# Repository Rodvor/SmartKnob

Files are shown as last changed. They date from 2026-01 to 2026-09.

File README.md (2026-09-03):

**Smart haptic knob as computer (MacOS) HID**

Still in development.

## Build dependencies

The following older versions are the **known-good fallback**:

| Component | Version | Notes |
| --- | --- | --- |
| [Arduino IDE](https://www.arduino.cc/en/software) | 2.3.6 | Includes Arduino CLI 1.2.0 |
| [Espressif Arduino-ESP32](https://github.com/espressif/arduino-esp32) | 3.2.1 | Board: `ESP32 Dev Module` (`esp32:esp32:esp32`) |
| [NimBLE-Arduino](https://github.com/h2zero/NimBLE-Arduino) | 2.3.9 | Install through Arduino Library Manager |
| [TFT_eSPI](https://github.com/Bodmer/TFT_eSPI) | 2.5.43 | Install through Arduino Library Manager; configuration below is required |
| [Simple FOC](https://docs.simplefoc.com) | 2.3.5 | Install through Arduino Library Manager |

`Wire`, `LittleFS`, and FreeRTOS are supplied by the Arduino-ESP32 board package and do not need separate installation.

To restore the known-good versions with Arduino CLI:

```sh
arduino-cli core install esp32:esp32@3.2.1
arduino-cli lib install "NimBLE-Arduino@2.3.9" "TFT_eSPI@2.5.43" "Simple FOC@2.3.5"
```

After restoring TFT_eSPI, replace its `User_Setup.h` with the repository copy at [`config/TFT_eSPI_User_Setup.h`](config/TFT_eSPI_User_Setup.h).

### Current upgraded versions

Installed, compile-checked, and flash-verified on 2026-09-03:

| Component | Current version |
| --- | --- |
| Espressif Arduino-ESP32 | 3.3.11 |
| NimBLE-Arduino | 2.5.1 |
| TFT_eSPI | 2.5.43 (already current) |
| Simple FOC | 2.4.0 |

The complete upgraded set compiles successfully for `ESP32 Dev Module`. ESP32 core 3.3.11 also compiles with the known-good older libraries, but upgrading ESP32 and Simple FOC together is recommended because Simple FOC 2.4.0 explicitly adds compatibility with all Arduino-ESP32 3.x releases.

NimBLE-Arduino 2.4 and newer starts registered HID services through `NimBLEServer::start()`. Its old `NimBLEHIDDevice::startServices()` method is deprecated and scheduled for removal. `NimbleKeyboard.h` detects the NimBLE generation: it uses the server method with the current library, but retains the HID-specific call when compiling against the fallback NimBLE 2.3.9.

Compilation and flash verification prove API compatibility and image integrity, but not the hardware behavior. Before making the newer versions the new baseline, test Bluetooth pairing/reconnection, fine volume adjustment, display output, motor direction, and haptic torque on the physical device. Simple FOC 2.4.0 changes ESP32 PWM safety/timing and velocity calculation, while ESP32 core 3.3.11 moves from ESP-IDF 5.4 to 5.5.5.

### Duplicate library files after an update

If a build error names files such as `HybridStepperMotor 2.cpp` or `NimBLEDevice 2.cpp`, the Arduino library directory contains duplicate conflict copies. Arduino compiles every `.cpp` file below a library's `src` directory, so these old copies are compiled alongside the newly installed version and cause duplicate definitions or incompatible APIs.

Move the `* 2.cpp` and `* 2.h` files out of the active library directory, or remove and cleanly reinstall that library. Do not fix this by editing the duplicated source files: they are stale library copies rather than project code.

### TFT_eSPI configuration

TFT_eSPI uses a library-level configuration that can be overwritten by an update or reinstall. The canonical setup is stored in [`config/TFT_eSPI_User_Setup.h`](config/TFT_eSPI_User_Setup.h); copy it over `Arduino/libraries/TFT_eSPI/User_Setup.h`.

```cpp
#define GC9A01_DRIVER

#define TFT_CS    5
#define TFT_DC    4
#define TFT_RST   0
#define TFT_MOSI  16
#define TFT_SCLK  15
#define TFT_BL    2

#define LOAD_GLCD
#define LOAD_FONT2
#define LOAD_FONT4
#define LOAD_FONT6
#define LOAD_FONT7
#define LOAD_FONT8
#define LOAD_GFXFF
#define SMOOTH_FONT
#define SPI_FREQUENCY       27000000
#define SPI_READ_FREQUENCY  20000000
#define SPI_TOUCH_FREQUENCY 2500000
```

ESP32 to drive TFT touch display
SimpleFOC mini v1.0 to drive brushless motor
AS5600 magnetic encoder to read brushless motor angle

ESP32 works as a bluetooth keyboard and takes input from dial and touch input from screen. 
Screen next to knob models are final for now.

**Current controls:**
- Move between menus using swipe gesture left or right
- Volume menu: Dial for adjustment, tap for play/pause
- Discord menu: Dial for unmute, mute, deafen and tap for leaving VC
- Brightness menu: Dial for adjusting screen brightness
- Media menu: Dial for skip/previous media track, and tap for play/pause.

Volume and media are controlled using dedicated buttons e.g. KEY_MEDIA_VOLUME_UP

**Brightness (Mac):** 
- Up: F15
- Down: F14

**Keybinds for Discord (Configured in Discord Keybinds):**
- F13 -> Mute
- Alt + F13 -> Deafen
- Shift + Alt + F13 -> Disconnect

Images are from google and no rights have been requested. Personal use only.

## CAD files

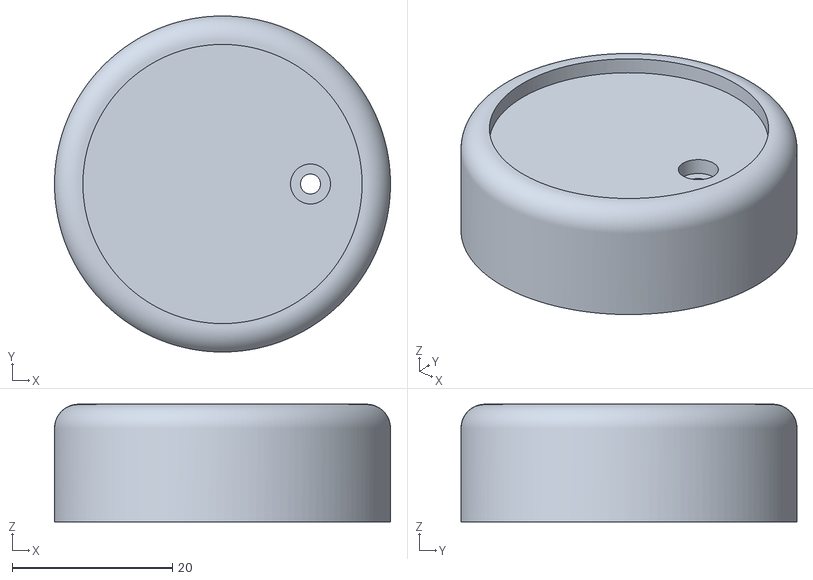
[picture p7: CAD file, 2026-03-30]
models/Dial and screen/Knob.stl
42.0 x 42.0 x 14.7

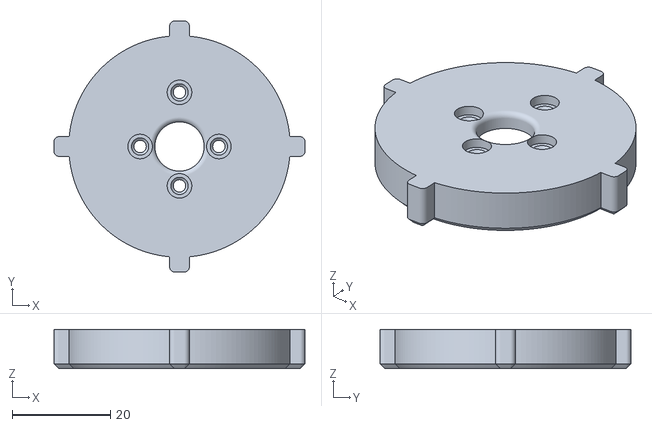
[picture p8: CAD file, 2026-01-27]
models/Dial on screen/Rotation base.stl
51.0 x 51.0 x 8.00

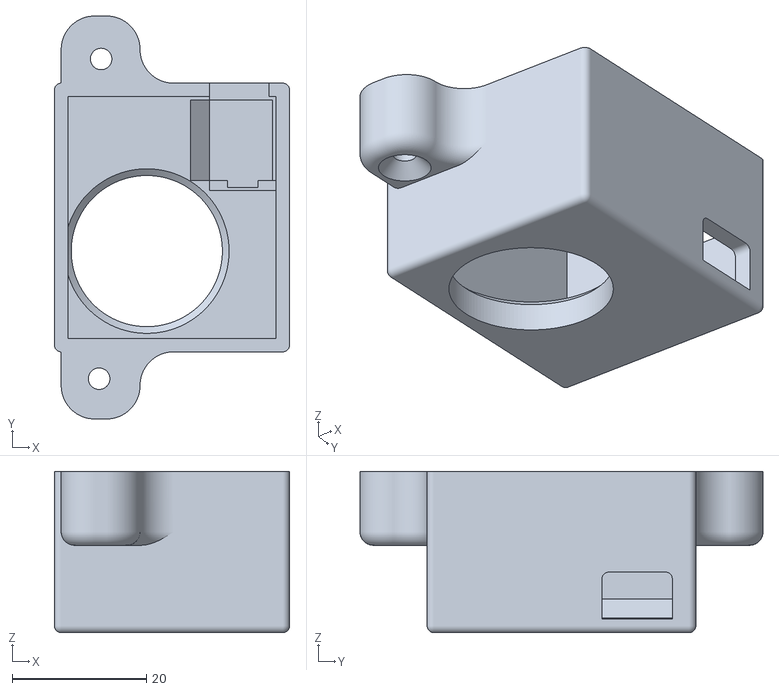
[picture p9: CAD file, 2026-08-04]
models/Knob powerbox.stl
35.0 x 60.0 x 24.0

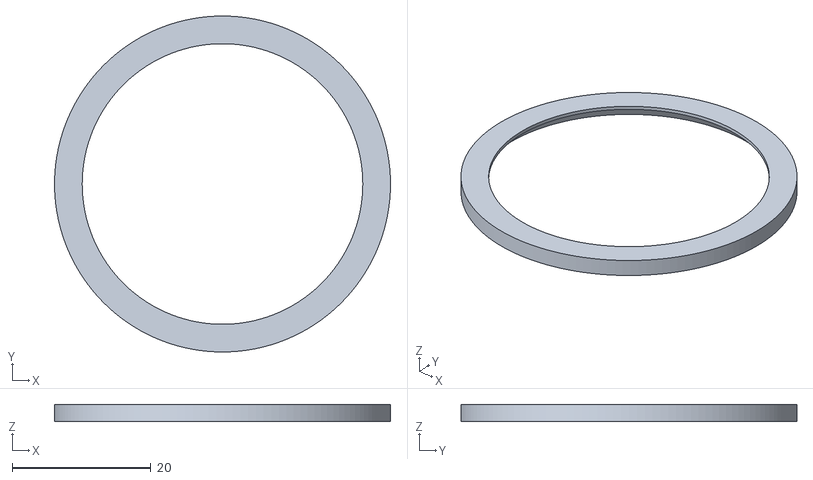
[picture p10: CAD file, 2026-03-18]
models/Dial and screen/Screen cover.stl
48.5 x 48.5 x 2.50

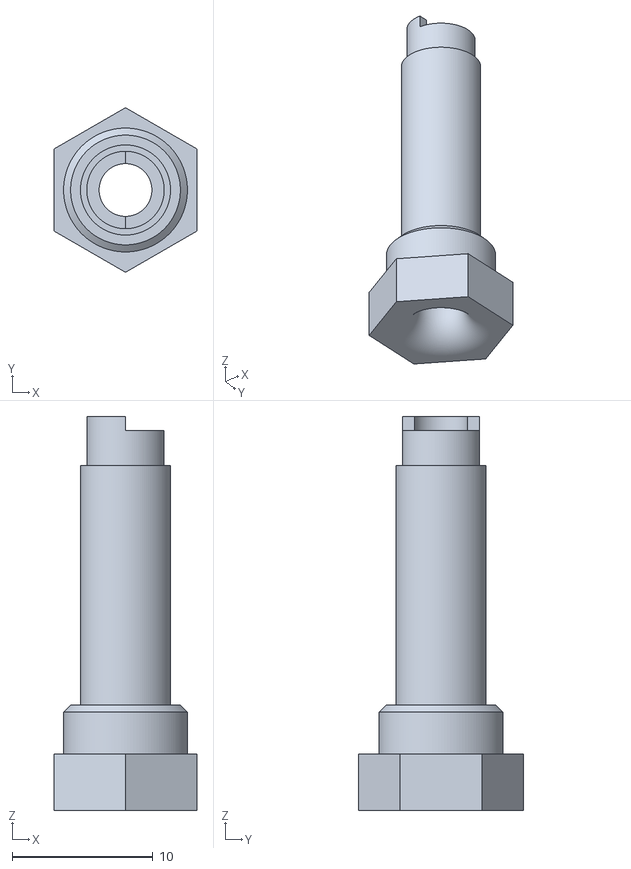
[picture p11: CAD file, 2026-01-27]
models/Dial on screen/Axle.stl
10.1 x 11.7 x 28.0

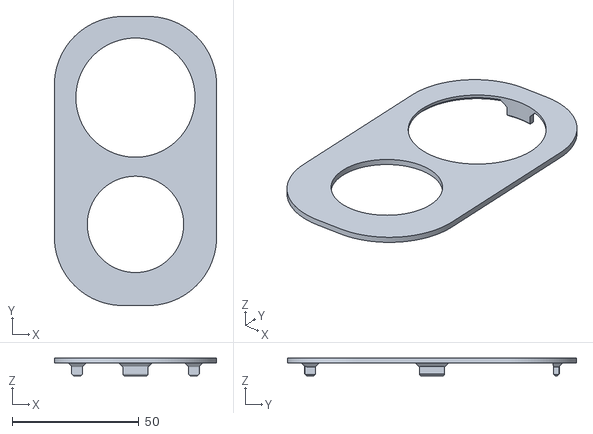
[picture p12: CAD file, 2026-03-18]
models/Dial and screen/Lid.stl
64.0 x 114.0 x 7.00

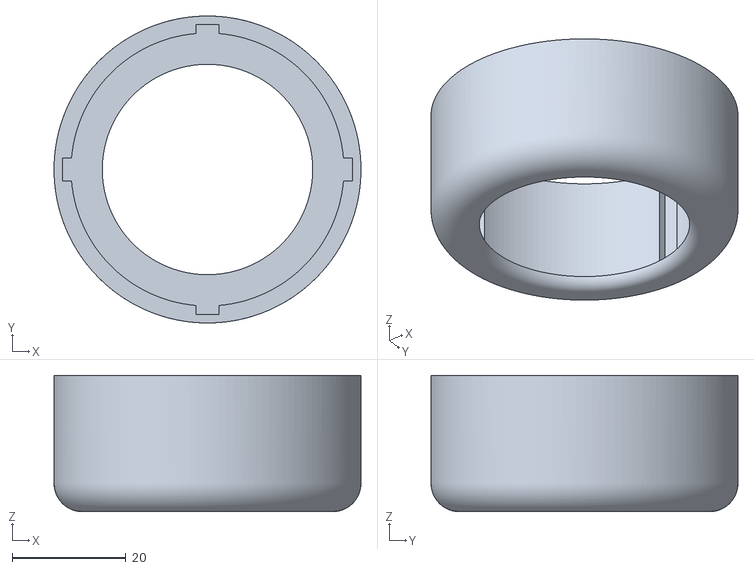
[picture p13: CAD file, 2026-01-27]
models/Dial on screen/dial.stl
54.0 x 54.0 x 24.0

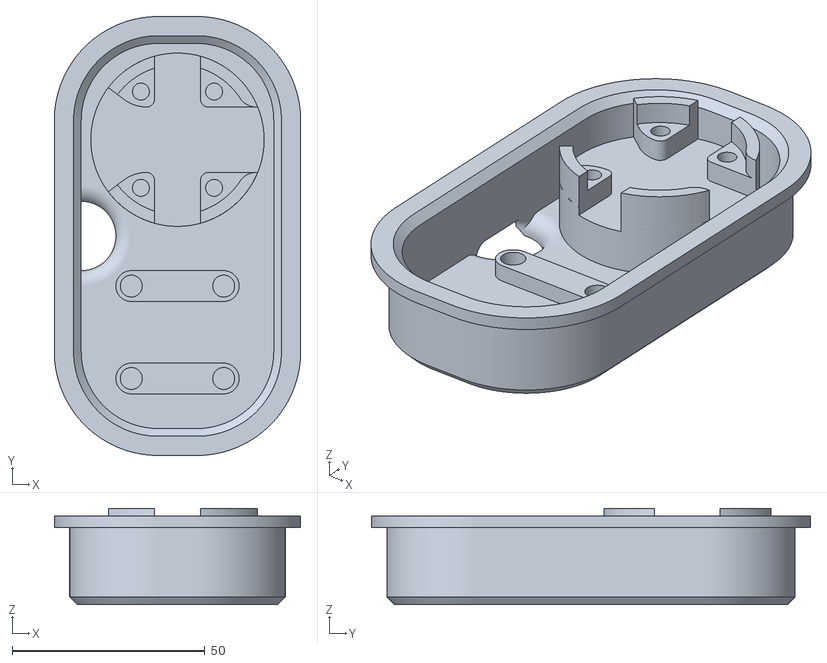
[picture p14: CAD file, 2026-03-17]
models/Dial and screen/Case.stl
64.0 x 114.0 x 25.0

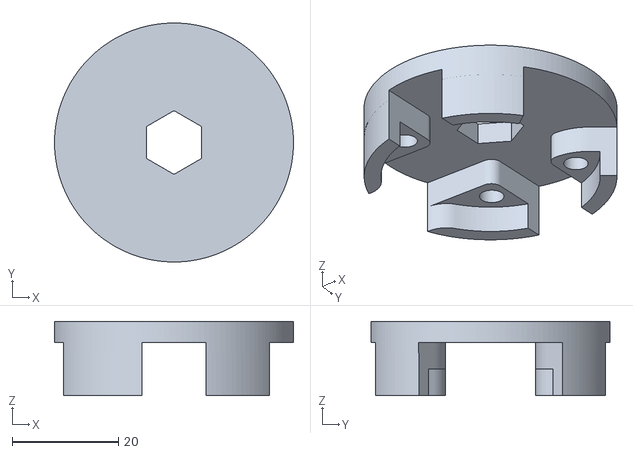
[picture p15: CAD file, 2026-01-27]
models/Dial on screen/Axle plate.stl
45.0 x 45.0 x 14.0

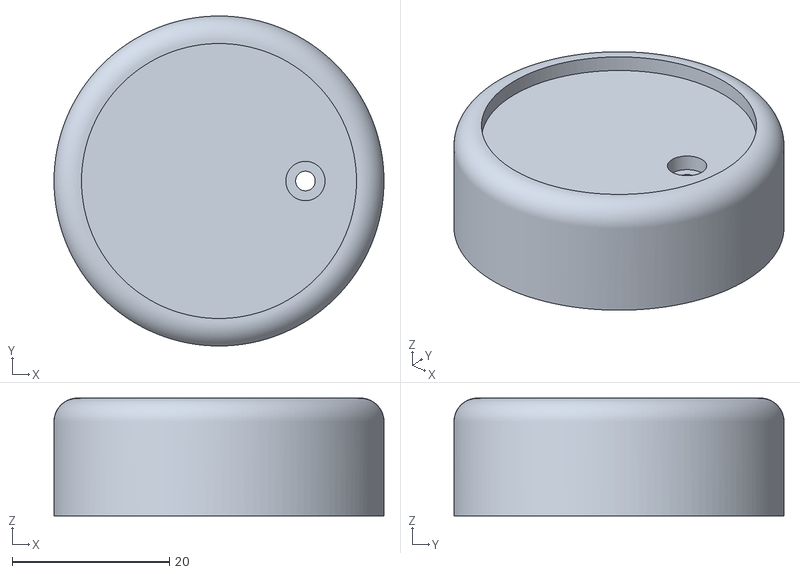
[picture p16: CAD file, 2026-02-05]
models/Dial and screen/Dial.stl
42.0 x 42.0 x 15.0

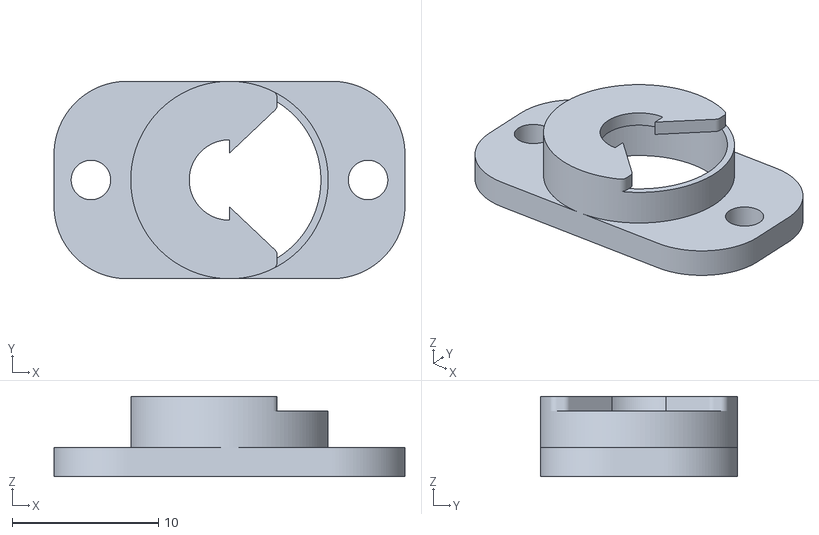
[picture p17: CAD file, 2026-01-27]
models/Dial on screen/Axle holder.stl
24.0 x 13.5 x 5.50

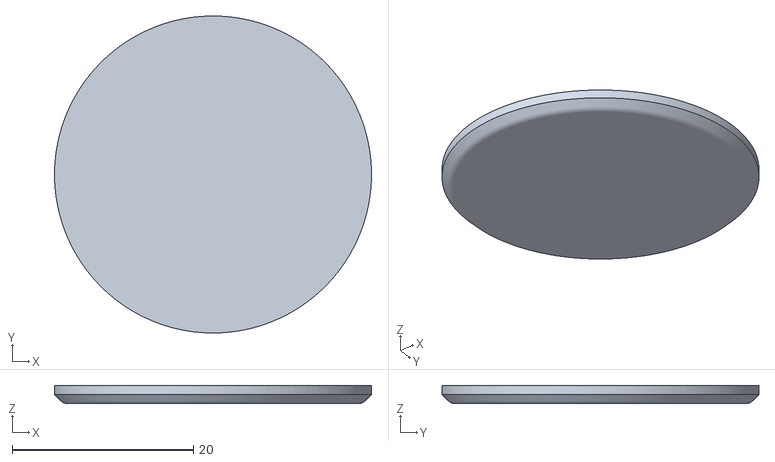
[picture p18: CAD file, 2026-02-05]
models/Dial and screen/Dial face.stl
35.0 x 35.0 x 2.00

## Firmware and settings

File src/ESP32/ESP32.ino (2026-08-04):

// Note: Colors for fonts using RGB565

// Include libraries
#include <TFT_eSPI.h>
#include <Wire.h>
#include <SimpleFOC.h>
#include <math.h>
#include "NimBLEKeyboard.h"

// Include configurations and icons
#include "menu_config.h"
#include "pin_config.h"
#include "icons.h"

#define CST816S_ADDR        0x15
#define CST816S_FINGER_REG  0x02
#define CST816S_X_HIGH_REG  0x03
#define CST816S_X_LOW_REG   0x04
#define CST816S_SWIPE_THRESHOLD 40

// Minimum torque. No torque if below this number
#define MINIMUM_TORQUE  0.1

// Moving ball sprite

#define BALL_RADIUS       5
#define BALL_SPRITE_SIZE  40   // 2*(BALL_RADIUS+margin) + headroom for movement per frame
#define SCREEN_SIZE       240  // adjust if your panel isn't 240x240
#define SPRITE_TRANSPARENT 0xF81F  // magenta marker, unused elsewhere in the UI

// Define objects
MagneticSensorI2C encoder = MagneticSensorI2C(AS5600_I2C);
TFT_eSPI tft = TFT_eSPI();
BLDCMotor motor = BLDCMotor(7);
BLDCDriver3PWM driver = BLDCDriver3PWM(IN1, IN2, IN3, EN);
NimBLEKeyboard bleKeyboard;

TFT_eSprite ballSprite = TFT_eSprite(&tft);

// For notches
const int cx = 120;
const int cy = 120;
const int radius = 120;
const int lineLength = 7;

// For motor calculations
float currentPos = 0;
float max_torque = 0.3;
float torque_build_up = 0.8;
int current_choice = 0;

// For UI logic
bool display_status = true;
bool take_input = false;
unsigned long last_activity = 0;
int current_ui_id = -1;
int new_ui_id = VOLUME_ID;
int n_lines = VOLUME_NOTCHES;
int discord_choice = 0;

const int CHOICES[] = {VOLUME_ID, MEDIA_ID, BRIGHT_ID, DISCORD_ID};
const int N_CHOICES = 4;
int current_menu_index = 0;

unsigned long last_touch_time = 0;
const unsigned long TOUCH_DEBOUNCE_MS = 300;
bool touch_active = false;
int touch_start_x = -1;
int touch_end_x = -1;

float sleep_pos = 0;
#define WAKE_ROTATION_THRESHOLD (PI / 60.0)

TaskHandle_t focTask;

void focLoop(void* param) {
  for (;;) {
    motor.loopFOC();
    vTaskDelay(1);
  }
}

uint8_t readTouchReg(uint8_t reg) {
  Wire.beginTransmission(CST816S_ADDR);
  Wire.write(reg);
  Wire.endTransmission(false);
  Wire.requestFrom(CST816S_ADDR, (uint8_t)1);
  if (Wire.available()) return Wire.read();
  return 0;
}

uint8_t readTouchFingers() { return readTouchReg(CST816S_FINGER_REG); }

int readTouchX() {
  uint8_t hi = readTouchReg(CST816S_X_HIGH_REG) & 0x0F;
  uint8_t lo = readTouchReg(CST816S_X_LOW_REG);
  return (hi << 8) | lo;
}

void dumpBleLog() {
  if (!LittleFS.begin(false)) return;
  fs::File f = LittleFS.open("/ble_log.txt", "r");
  if (!f) {
    Serial.println("No BLE log found.");
    return;
  }
  Serial.println("=== BLE LOG ===");
  while (f.available()) {
    Serial.write(f.read());
  }
  Serial.println("=== END LOG ===");
  f.close();
}

void setup() {
  Serial.begin(115200);
  //delay(500); // give Serial monitor time to connect
  //dumpBleLog();

  bleKeyboard.begin("Haptic Knob");

  // Set blacklight pins
  pinMode(BLK_PIN, OUTPUT);
  digitalWrite(BLK_PIN, HIGH);

  // Init screen
  tft.init();
  tft.fillScreen(TFT_BLACK);
  tft.setFreeFont(&FreeSans12pt7b);
  tft.setTextDatum(MC_DATUM);
  tft.setTextColor(0xad75);
  // Ball sprite
  ballSprite.setColorDepth(16);
  ballSprite.createSprite(BALL_SPRITE_SIZE, BALL_SPRITE_SIZE);

  // Bluetooth connecting screen
  tft.fillScreen(TFT_BLACK);
  tft.drawBitmap(ICON_X, ICON_Y, icon_bluetooth, ICON_W, ICON_H, BLUETOOTH_COLOR);
  tft.drawString("Connecting...", 122, 180);


  Wire.begin(ENCODER_SDA, ENCODER_SCL);
  encoder.init();

  pinMode(TP_RST, OUTPUT);
  digitalWrite(TP_RST, LOW);
  delay(10);
  digitalWrite(TP_RST, HIGH);
  delay(50);
  pinMode(TP_INT, INPUT);
  Wire1.begin(TP_SDA, TP_SCL);

  driver.voltage_power_supply = 12.0;
  driver.init();
  motor.linkDriver(&driver);
  motor.linkSensor(&encoder);
  motor.controller = MotionControlType::torque;
  motor.torque_controller = TorqueControlType::voltage;
  motor.voltage_limit = 3.0;
  motor.init();
  motor.initFOC();

  xTaskCreatePinnedToCore(focLoop, "FOC", 4096, NULL, 1, &focTask, 1);

  while (!bleKeyboard.isConnected()) {
    delay(500);
  }

  Serial.println("BLE connected, starting UI");
}

void doTapAction() {
  if (!bleKeyboard.isConnected()) return;
  if      (current_ui_id == VOLUME_ID)  bleKeyboard.playPause();
  else if (current_ui_id == MEDIA_ID)   bleKeyboard.playPause();
  else if (current_ui_id == DISCORD_ID) bleKeyboard.pressShiftAltF13();
  // BRIGHT_ID: no tap action
}

void swipeToMenu(int direction) {
  current_menu_index = (current_menu_index + direction + N_CHOICES) % N_CHOICES;
  new_ui_id = CHOICES[current_menu_index];
  last_activity = millis();
}

void handleTouchRevised() {
  unsigned long now = millis();
  uint8_t fingers = readTouchFingers();

  if (fingers >= 1) {
    int x = readTouchX();
    if (!touch_active) { touch_active = true; touch_start_x = x; }
    touch_end_x = x;
  } else {
    if (touch_active) {
      touch_active = false;
      if (now - last_touch_time < TOUCH_DEBOUNCE_MS) return;
      last_touch_time = now;

      if (!display_status) {
        setDisplay(true);
        last_activity = now;
        return;
      }

      int dx = touch_end_x - touch_start_x;
      if      (dx >  CST816S_SWIPE_THRESHOLD) swipeToMenu(+1);
      else if (dx < -CST816S_SWIPE_THRESHOLD) swipeToMenu(-1);
      else { doTapAction(); last_activity = now; }
    }
  }
}

void loop() {
  handleTouchRevised();

  if (new_ui_id != current_ui_id) {
    drawUI(new_ui_id);
    take_input = false;
  }

  float pos = encoder.getAngle();
  int choice = calc_choice(pos);

  if (take_input) {
    motor.move(calc_torque(pos));
  } else {
    float target_angle = 0;
    if (current_ui_id == DISCORD_ID) target_angle = discord_choice * 2 * PI / 3;
    motor.move(torque_to_angle(pos, target_angle));
    if (abs(((target_angle - PI / 2) - pos)) < 0.05) {
      take_input = true;
      current_choice = choice;
    }
  }

  if (pos != currentPos) {

    if (!display_status && fabs(pos - sleep_pos) > WAKE_ROTATION_THRESHOLD) {
      setDisplay(true);
      last_activity = millis();
    }

    drawBall(currentPos, pos);

    int new_choice = calc_choice(pos);

    if (new_choice != current_choice && take_input) {
      if (pos > currentPos) {
        if      (current_ui_id == VOLUME_ID)  bleKeyboard.volumeUp();
        else if (current_ui_id == MEDIA_ID)   bleKeyboard.nextTrack();
        else if (current_ui_id == BRIGHT_ID)  bleKeyboard.pressF15();
      } else {
        if      (current_ui_id == VOLUME_ID)  bleKeyboard.volumeDown();
        else if (current_ui_id == MEDIA_ID)   bleKeyboard.prevTrack();
        else if (current_ui_id == BRIGHT_ID)  bleKeyboard.pressF14();
      }

      if (current_ui_id == DISCORD_ID) {
        if (new_choice == 0) {
          bleKeyboard.pressF13();
        } else if (new_choice == 1 && current_choice == 0) {
          bleKeyboard.pressF13();
        } else if (new_choice == 2 && current_choice == 0) {
          bleKeyboard.pressF13(); delay(20); bleKeyboard.pressAltF13();
        } else {
          bleKeyboard.pressAltF13();
        }
        discord_choice = new_choice;
      }

      if (!display_status) setDisplay(true);
      last_activity = millis();
      current_choice = new_choice;
    }

    currentPos = pos;
  }

  if (display_status && millis() - last_activity > IDLE_TIMEOUT * 60000) {
    setDisplay(false);
  }

  vTaskDelay(1); // yield instead of blocking delay
}

// --- UI ---

void drawMenuIcon(int id) {
  const uint8_t* bmp = nullptr;
  unsigned int color = TFT_WHITE;
  switch (id) {
    case VOLUME_ID:  bmp = icon_volume;     color = VOLUME_COLOR;  break;
    case MEDIA_ID:   bmp = icon_media;      color = MEDIA_COLOR;   break;
    case DISCORD_ID: bmp = icon_discord;    color = DISCORD_COLOR; break;
    case BRIGHT_ID:  bmp = icon_brightness; color = BRIGHT_COLOR;  break;
  }
  if (bmp) {
    tft.drawBitmap(ICON_X, ICON_Y, bmp, ICON_W, ICON_H, color);
  }
}

void drawSmallIcon(int id, int x, int y) {
  const uint8_t* bmp = nullptr;
  unsigned int color = TFT_WHITE;
  switch (id) {
    case UNMUTE_ID:  bmp = icon_unmute;   color = UNMUTE_COLOR;  break;
    case MUTE_ID:   bmp = icon_mute;      color = MUTE_COLOR;   break;
    case DEAFEN_ID: bmp = icon_deafen;    color = DEAFEN_COLOR; break;
  }
  if (bmp) {
    tft.drawBitmap(x, y, bmp, SMALL_ICON_W, SMALL_ICON_H, color);
  }
}

void drawUI(int id) {
  tft.fillScreen(TFT_BLACK);
  current_ui_id = id;
  drawMenuIcon(id);
  tft.setFreeFont(&FreeSans12pt7b);
  tft.setTextDatum(MC_DATUM);
  tft.setTextColor(0xad75);
  if      (id == VOLUME_ID)  { tft.drawString("Volume",     120, 180); max_torque = VOLUME_TORQUE;  torque_build_up = VOLUME_BUILDUP;  n_lines = VOLUME_NOTCHES; }
  else if (id == MEDIA_ID)   { tft.drawString("Media",      120, 180); max_torque = MEDIA_TORQUE;   torque_build_up = MEDIA_BUILDUP;   n_lines = MEDIA_NOTCHES; }
  else if (id == DISCORD_ID) { 
    tft.drawString("Discord", 120, 180);
    drawSmallIcon(UNMUTE_ID, 108, 30);
    drawSmallIcon(MUTE_ID, 178, 155);
    drawSmallIcon(DEAFEN_ID, 44, 155);
    max_torque = DISCORD_TORQUE; 
    torque_build_up = DISCORD_BUILDUP; 
    n_lines = DISCORD_NOTCHES; 
    }
  else if (id == BRIGHT_ID)  { tft.drawString("Brightness", 120, 180); max_torque = BRIGHT_TORQUE;  torque_build_up = BRIGHT_BUILDUP;  n_lines = BRIGHT_NOTCHES; }
  drawClockLines();
}

void drawClockLines() {
  for (int i = 0; i < n_lines; i++) {
    float angle = i * (2.0 * PI / n_lines) - PI / 2;
    int x0 = round(cx + radius * cos(angle));
    int y0 = round(cy + radius * sin(angle));
    int x1 = round(cx + (radius - lineLength) * cos(angle));
    int y1 = round(cy + (radius - lineLength) * sin(angle));
    tft.drawLine(x0, y0, x1, y1, 0x9492);
  }
}

float calc_torque(float pos) {
  const float amplitude = torque_build_up * max_torque;
  const float inside_tan = 0.5 * n_lines * (pos + PI / 2);
  float torque = amplitude * tan(inside_tan);

  if (abs(torque) < MINIMUM_TORQUE) return 0.0;
  if (torque > max_torque) return max_torque;
  if (torque < -max_torque) return -max_torque;
  return torque;
}

float torque_to_angle(float pos, float angle) {
  return 0.5 * cbrt(pos + PI / 2 - angle);
}

int calc_choice(float pos) {
  float angle = pos + PI / 2;
  while (angle < 0) angle += 2 * PI;
  while (angle >= 2 * PI) angle -= 2 * PI;
  return ((int)round(angle / (2.0 * PI) * n_lines)) % n_lines;
}

void drawBall(float posOld, float posNew) {
  int xOld = round(cx + (radius - 18) * cos(posOld));
  int yOld = round(cy + (radius - 18) * sin(posOld));
  int xNew = round(cx + (radius - 18) * cos(posNew));
  int yNew = round(cy + (radius - 18) * sin(posNew));

  const int margin = 2;
  int minX = min(xOld, xNew) - BALL_RADIUS - margin;
  int minY = min(yOld, yNew) - BALL_RADIUS - margin;
  int maxX = max(xOld, xNew) + BALL_RADIUS + margin;
  int maxY = max(yOld, yNew) + BALL_RADIUS + margin;
  int w = maxX - minX;
  int h = maxY - minY;

  if (w <= BALL_SPRITE_SIZE && h <= BALL_SPRITE_SIZE) {
    minX = constrain(minX, 0, SCREEN_SIZE - BALL_SPRITE_SIZE);
    minY = constrain(minY, 0, SCREEN_SIZE - BALL_SPRITE_SIZE);

    ballSprite.fillSprite(SPRITE_TRANSPARENT);
    ballSprite.fillCircle(xOld - minX, yOld - minY, BALL_RADIUS, TFT_BLACK);
    ballSprite.fillCircle(xNew - minX, yNew - minY, BALL_RADIUS, TFT_WHITE);
    ballSprite.pushSprite(minX, minY, SPRITE_TRANSPARENT);
  } else {
    tft.fillCircle(xOld, yOld, BALL_RADIUS, TFT_BLACK);
    tft.fillCircle(xNew, yNew, BALL_RADIUS, TFT_WHITE);
  }
}

void setDisplay(bool onoff) {
  display_status = onoff;
  if (!onoff) sleep_pos = encoder.getAngle();
  digitalWrite(BLK_PIN, onoff ? HIGH : LOW);
}

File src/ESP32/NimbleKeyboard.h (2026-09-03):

#pragma once

#include <NimBLEDevice.h>
#include <NimBLEServer.h>
#include <NimBLEUtils.h>
#include <NimBLEHIDDevice.h>
#if __has_include(<NimBLECppVersion.h>)
#include <NimBLECppVersion.h>
#define SMARTKNOB_HAS_NIMBLE_VERSION_HEADER 1
#endif
#include <HIDTypes.h>
#include <LittleFS.h>
#include <atomic>
#include <freertos/queue.h>

// Consumer key codes
#define KEY_MEDIA_VOLUME_UP      0xE9
#define KEY_MEDIA_VOLUME_DOWN    0xEA
#define KEY_MEDIA_PLAY_PAUSE     0xCD
#define KEY_MEDIA_NEXT_TRACK     0xB5
#define KEY_MEDIA_PREVIOUS_TRACK 0xB6

// HID report descriptor: keyboard + consumer control
static const uint8_t hidReportDescriptor[] = {
  // Keyboard
  0x05, 0x01,  // Usage Page: Generic Desktop
  0x09, 0x06,  // Usage: Keyboard
  0xA1, 0x01,  // Collection: Application
  0x85, 0x01,  //   Report ID: 1
  0x05, 0x07,  //   Usage Page: Keyboard
  0x19, 0xE0,  //   Usage Minimum: Left Control
  0x29, 0xE7,  //   Usage Maximum: Right GUI
  0x15, 0x00,  //   Logical Minimum: 0
  0x25, 0x01,  //   Logical Maximum: 1
  0x75, 0x01,  //   Report Size: 1
  0x95, 0x08,  //   Report Count: 8
  0x81, 0x02,  //   Input: Data, Variable, Absolute (modifier keys)
  0x95, 0x01,  //   Report Count: 1
  0x75, 0x08,  //   Report Size: 8
  0x81, 0x03,  //   Input: Constant (reserved)
  0x95, 0x06,  //   Report Count: 6
  0x75, 0x08,  //   Report Size: 8
  0x15, 0x00,  //   Logical Minimum: 0
  0x25, 0x73,  //   Logical Maximum: 115
  0x05, 0x07,  //   Usage Page: Keyboard
  0x19, 0x00,  //   Usage Minimum: 0
  0x29, 0x73,  //   Usage Maximum: 115
  0x81, 0x00,  //   Input: Data, Array
  0xC0,        // End Collection

  // Consumer Control
  0x05, 0x0C,  // Usage Page: Consumer
  0x09, 0x01,  // Usage: Consumer Control
  0xA1, 0x01,  // Collection: Application
  0x85, 0x02,  //   Report ID: 2
  0x15, 0x00,  //   Logical Minimum: 0
  0x26, 0xFF, 0x03, // Logical Maximum: 1023
  0x19, 0x00,  //   Usage Minimum: 0
  0x2A, 0xFF, 0x03, // Usage Maximum: 1023
  0x75, 0x10,  //   Report Size: 16
  0x95, 0x01,  //   Report Count: 1
  0x81, 0x00,  //   Input: Data, Array
  0xC0         // End Collection
};

// Modifier bitmasks
#define MOD_LEFT_CTRL   0x01
#define MOD_LEFT_SHIFT  0x02
#define MOD_LEFT_ALT    0x04
#define MOD_LEFT_GUI    0x08

// Keep Shift+Option held between volume ticks. They are released after this
// much time without a new volume turn.
static constexpr uint32_t VOLUME_MODIFIER_IDLE_RELEASE_MS = 500;

// Key codes (subset)
#define HID_KEY_F13  0x68
#define HID_KEY_F14  0x69
#define HID_KEY_F15  0x6A

class NimBLEKeyboard : public NimBLEServerCallbacks, public NimBLECharacteristicCallbacks {
public:
  NimBLEServer*    pServer    = nullptr;
  NimBLEHIDDevice* hid        = nullptr;
  NimBLECharacteristic* input = nullptr;
  NimBLECharacteristic* consumer = nullptr;

  uint32_t connectedSince = 0;
  bool loggingReady = false;

  static const size_t MAX_LOG_SIZE = 8192;

  void logEvent(const char* msg) {
    if (!loggingReady) return;
    fs::File f = LittleFS.open("/ble_log.txt", "a");
    if (!f) return;
    // Check size and truncate if too large
    if (f.size() > MAX_LOG_SIZE) {
      f.close();
      LittleFS.remove("/ble_log.txt");
      f = LittleFS.open("/ble_log.txt", "a");
      if (!f) return;
      f.println("[log truncated]");
    }
    unsigned long s = millis() / 1000;
    unsigned long m = s / 60;
    unsigned long h = m / 60;
    f.printf("[%02lu:%02lu:%02lu] %s\n", h % 100, m % 60, s % 60, msg);
    f.close();
  }

  void onConnect(NimBLEServer* s, NimBLEConnInfo& info) override {
    connected.store(false);
    keyboardSubscribed.store(false);
    consumerSubscribed.store(false);
    connectionGeneration.fetch_add(1);
    if (reportQueue) xQueueReset(reportQueue);
    connHandle.store(info.getConnHandle());
    connectedSince = millis();
    connected.store(true);
    Serial.println("BLE connected");
    logEvent("Connected");
    // Let the host choose connection parameters. Forcing a renegotiation here has
    // caused timeout disconnects with macOS.
  }

  void onDisconnect(NimBLEServer* s, NimBLEConnInfo& info, int reason) override {
    connected.store(false);
    keyboardSubscribed.store(false);
    consumerSubscribed.store(false);
    connectionGeneration.fetch_add(1);
    if (reportQueue) xQueueReset(reportQueue);
    uint32_t duration = (millis() - connectedSince) / 1000;
    char buf[80];
    snprintf(buf, sizeof(buf), "Disconnected reason=0x%02X, duration=%lus", reason, duration);
    Serial.println(buf);
    logEvent(buf);
  }

  void onSubscribe(NimBLECharacteristic* chr, NimBLEConnInfo& info, uint16_t subValue) override {
    const bool notificationsEnabled = (subValue & 0x01) != 0;
    if (chr == input) {
      keyboardSubscribed.store(notificationsEnabled);
      if (notificationsEnabled) enqueueRelease(input, 8);
    } else if (chr == consumer) {
      consumerSubscribed.store(notificationsEnabled);
      if (notificationsEnabled) enqueueRelease(consumer, 2);
    }
  }
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

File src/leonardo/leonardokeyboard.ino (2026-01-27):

/*
  Rotary encoder as HID media controller (macOS compatible)
  ---------------------------------------------------------
  Rotation:  volume up/down  (with Shift + Option)
  Button:
    - Single click → F13
    - Hold (>0.5 s) → pause/play immediately

  

  Switch: F13
*/

#include <HID-Project.h>
#include <SoftwareSerial.h>

SoftwareSerial espSerial(8, 9); // RX, TX

#define CLK 2
#define DT 3
#define SW 4
#define SWITCH_PIN 6


int lastCLK;
int lastSW;

// --- click timing ---
bool buttonPressed = false;
bool isHold = false;

bool switchState = false;
bool lastSwitchState = false;
unsigned long lastSwitchChange = 0;
const unsigned long debounceTime = 30;
static unsigned long lastKeepalive = 0;





void setup() {

  Consumer.begin();
  BootKeyboard.begin();

  pinMode(CLK, INPUT_PULLUP);
  pinMode(DT, INPUT_PULLUP);
  pinMode(SW, INPUT_PULLUP);

  lastCLK = digitalRead(CLK);
  lastSW  = digitalRead(SW);

  pinMode(SWITCH_PIN, INPUT_PULLUP);
  switchState = !digitalRead(SWITCH_PIN);
  lastSwitchState = switchState;

  Serial.begin(115200); // USB debug
  espSerial.begin(57600);

}






void loop() {

  // ---- Rotary push button ----
  int currentSW = digitalRead(SW);
  unsigned long now = millis();

  // Button pressed
  if (currentSW == LOW && !buttonPressed) {
    buttonPressed = true;
  }

  // Button released
  if (currentSW == HIGH && buttonPressed) {
    buttonPressed = false;

    if (!isHold) {
      clickEncoder(); // only click
    }

    isHold = false;

    delay(50);

  }

  lastSW = currentSW;


  // Encoder rotation
  int currentCLK = digitalRead(CLK);
  if (currentCLK != lastCLK) {
    if (digitalRead(DT) != currentCLK) {

      if (!buttonPressed) {
        // Only rotation
        volumeUp();
      } else {
        // Press and rotate
        skipNext();
        isHold = true;
      }
    } else {
      if (!buttonPressed) {
        // Only rotation
        volumeDown();
      } else {
        // Press and rotate
        skipPrevious();
        isHold = true;
      }
    }
  }
  lastCLK = currentCLK;





  // ---- On/Off Toggle Switch ----
  bool raw = !digitalRead(SWITCH_PIN);

  if (raw != lastSwitchState && (now - lastSwitchChange) > debounceTime) {
      lastSwitchChange = now;
      lastSwitchState = raw;

      if (raw != switchState) {
          switchState = raw;

          if (switchState) {
              switchOn();
          } else {
              switchOff();
          }
      }
  }

  // Function for keeping HID connected

  if (millis() - lastKeepalive > 30000) {
    BootKeyboard.releaseAll();
    lastKeepalive = millis();
  }

  if (espSerial.available()) {
    String cmd = espSerial.readStringUntil('\n');

    handleCommand(cmd);
  }
}

// ------------------------------------------------------
// Helper functions
// ------------------------------------------------------

void handleCommand(String c) {
  Serial.print("Handling: ");
  Serial.println(c);

  if (c.indexOf("volume-up") != -1) {
    volumeUp();
  } 
  else if (c.indexOf("volume-down") != -1) {
    volumeDown();
  }
  else if (c.indexOf("skip") != -1) {
    skipNext();
  }
  else if (c.indexOf("previous") != -1) {
    skipPrevious();
  }
  else if (c.indexOf("mute-and-deafen") != -1) {
    clickF13();
    delay(20);
    clickAltF13();
  }
  else if (c.indexOf("mute") != -1) {
    clickF13();
  }
  else if (c.indexOf("deafen") != -1) {
    clickAltF13();
  }
  else if (c.indexOf("bright-up") != -1) {
    clickF15();
  }
  else if (c.indexOf("bright-down") != -1) {
    clickF14();
  }
}

void volumeUp() {
  BootKeyboard.press(KEY_LEFT_SHIFT);
  BootKeyboard.press(KEY_LEFT_ALT);
  delay(5);
  Consumer.write(MEDIA_VOLUME_UP);
  delay(5);
  BootKeyboard.releaseAll();
}

void volumeDown() {
  BootKeyboard.press(KEY_LEFT_SHIFT);
  BootKeyboard.press(KEY_LEFT_ALT);
  delay(5);
  Consumer.write(MEDIA_VOLUME_DOWN);
  delay(5);
  BootKeyboard.releaseAll();
}

// Mute
void clickF13() {
  BootKeyboard.press(KEY_F13);
  delay(5);
  BootKeyboard.release(KEY_F13);
}

// Deafen
void clickAltF13() {
  BootKeyboard.press(KEY_LEFT_ALT);
  BootKeyboard.press(KEY_F13);
  delay(5);
  BootKeyboard.releaseAll();
}

// Brightness down
void clickF14() {
  BootKeyboard.press(KEY_F14);
  delay(5);
  BootKeyboard.release(KEY_F14);
}

// Brightness up
void clickF15() {
  BootKeyboard.press(KEY_F15);
  delay(5);
  BootKeyboard.release(KEY_F15);
}

void pauseMedia() {
  Consumer.write(MEDIA_PLAY_PAUSE);
}

void clickLeft() {
  BootKeyboard.press(KEY_LEFT_ARROW);
  delay(5);
  BootKeyboard.release(KEY_LEFT_ARROW);
}

void clickRight() {
  BootKeyboard.press(KEY_RIGHT_ARROW);
  delay(5);
  BootKeyboard.release(KEY_RIGHT_ARROW);
}


// Button and switch binding

// Switch on state
void switchOn() {
  clickF13();
}

// Switch off state
void switchOff() {
  clickF13();
}

// Click encoder once
void clickEncoder() {
  pauseMedia();
}

// Hold encoder
void holdEncoder() {
  clickF14();
}

void skipNext() {
  Consumer.write(MEDIA_NEXT);
}

void skipPrevious() {
  Consumer.write(MEDIA_PREVIOUS);
}

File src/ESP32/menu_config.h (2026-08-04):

#ifndef MENU_CONFIG_H
#define MENU_CONFIG_H

// x_TORQUE: Maximum torque that can be applied (Volts)
// x_BUILDUP: How quickly torque builds up to maximum
// x_NOTCHES: How many indents/choices in menu

//
// Menu definitions
//



// Volume menu
#define VOLUME_NOTCHES 30
#define VOLUME_TORQUE 0.5
#define VOLUME_BUILDUP 0.6
#define VOLUME_ID 0

// Media controls
#define MEDIA_NOTCHES 20
#define MEDIA_TORQUE 0.4
#define MEDIA_BUILDUP 0.5
#define MEDIA_ID 2

// Discord voice chat controls
#define DISCORD_NOTCHES 3
#define DISCORD_TORQUE 0.6
#define DISCORD_BUILDUP 1.5
#define DISCORD_ID 3

// Brightness controls
#define BRIGHT_NOTCHES 20
#define BRIGHT_TORQUE 0.4
#define BRIGHT_BUILDUP 0.4
#define BRIGHT_ID 4

#define IDLE_TIMEOUT 10 // Minutes until display sleep


#endif

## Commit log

2026-01-27 Initial commit
    First commit with prototype work
2026-01-27 Updated current leonardo software
    The software contains the code for the current setup. Will be removed once the SmartKnob has been physically installed
2026-02-05 Added first models of new design
    [Axle holder.stl, Axle plate.stl, Axle.stl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]
2026-02-13 Issue with pin 12 fixed
2026-03-17 Added case 3D model
    [Case.stl]
2026-03-18 Added 3D models and small fixes
    [Lid.stl, Screen cover.stl]
2026-03-18 Adjusted screen cover size
    [Screen cover.stl]
2026-03-18 Final adjustments for screen cover
    [Screen cover.stl]
2026-03-19 Fixed a bug where mac wakes from sleep
    [ESP32.ino, NimbleKeyboard.h]
2026-03-20 Further fixes on Mac wakeup from sleep
    [NimbleKeyboard.h]
2026-03-30 Added adjusted knob model
    [Knob.stl]
2026-08-04 Model for powerbox with on-off switch
    [Knob powerbox.stl]
2026-08-04 Torque adjustments
